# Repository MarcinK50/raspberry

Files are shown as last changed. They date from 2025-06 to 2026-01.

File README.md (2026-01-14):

# RPi Pico W + DHT22 + PMS5003 sensor

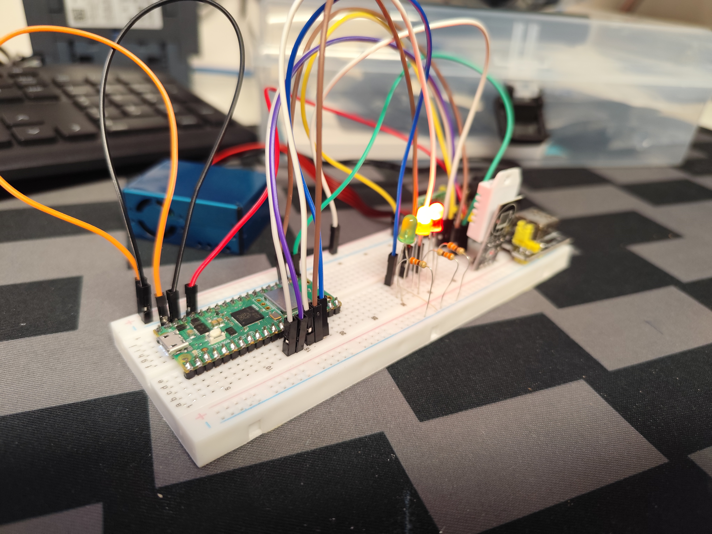
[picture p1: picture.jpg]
zdjecie


```
DHT22 - GPIO16
PMS5003 - TX GPIO8, RX GPIO9

status led:
power status (red) - GPIO10 
wifi status (yellow) - GPIO11
data status (green) - GPIO12
```

## Development branch - differences vs prod branch
- tables have `dev_` prefix
- another development dashboard on Grafana

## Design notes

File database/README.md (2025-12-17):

# Database
QuestDB database, set ip & port in config.py on sensor (default works on port 9000)

https://questdb.com/docs/quick-start/

## Database schema
- `config`
    - Columns:
    - `id` - sensor id `[int]`
    - `lat` - sensor latitude `[double]`
    - `lon` - sensor longitude `[double]`
    - `location` - sensor location, e.g. name of place or street `[string]`
    - `description` - more detalied info about sensor `[string]`
- `sensors`
    - Columns:
    - `timestamp`
    - `id` - sensor id corresponding with `id` from `config` table `[int]`
    - `temperature` `[double]`
    -  `humidity` `[double]`
    - `pm1` `[int]`
    - `pm25` `[int]`
    - `pm10` `[int]`
- `log` (work in progress)
    - Columns:
    - `id` `[int]`
    - `timestamp`
    - `code` - log message type, e.g. 0 - info, 1 - warning, 2 - error `[int]`
    - `message` - more detailed information `[string]`

## Quick configuration
Paste code from `configuration.sql` into QuestDB console to quickly create needed tables.

## Config example

```sql
INSERT INTO config (id, lat, lon, location, description) VALUES (0, 50.581867, 16.690958, 'Pracownia', 'Czujnik 1 w pracowni')
```

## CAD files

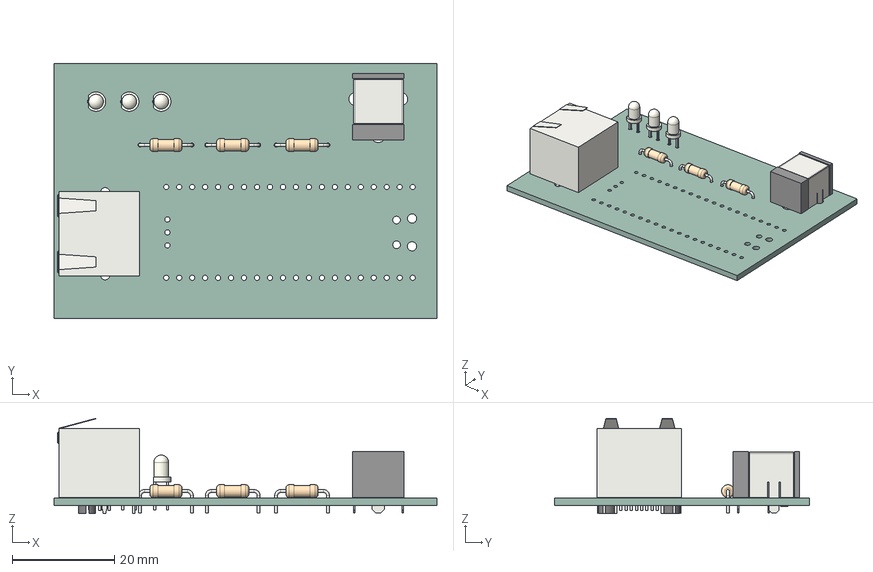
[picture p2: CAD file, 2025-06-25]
hardware/CAD/czujnik/czujnik.step
75.0 x 50.0 x 18.7 mm
BarrelJack_CUI_PJ-063AH_Horizontal
LED_D3.0mm_Clear x 3
Pico
RJ45_Amphenol_RJHSE538X
R_Axial_DIN0207_L6.3mm_D2.5mm_P10.16mm_Horizontal x 3
czujnik_PCB

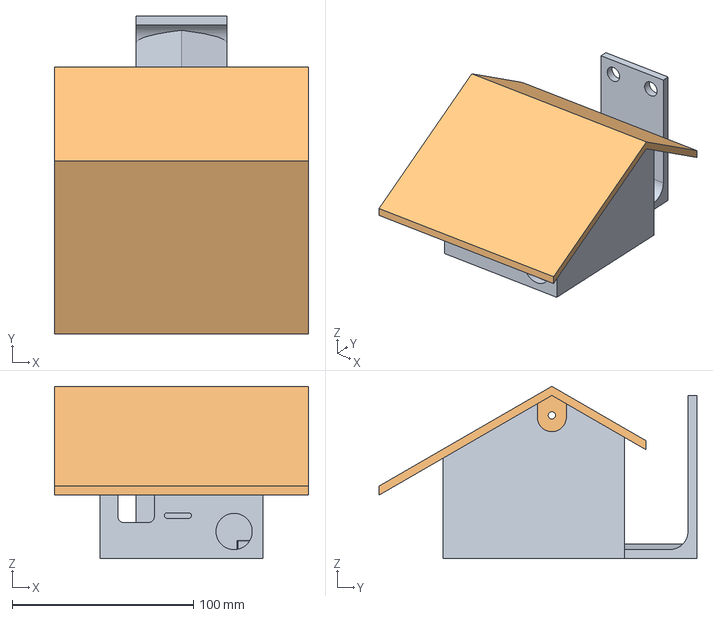
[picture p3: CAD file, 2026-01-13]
hardware/CAD/czujnik_external/Sensor_external.FCStd
140.0 x 175.3 x 95.0 mm
Cover
Roof

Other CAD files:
hardware/CAD/czujnik/czujnik.FCStd

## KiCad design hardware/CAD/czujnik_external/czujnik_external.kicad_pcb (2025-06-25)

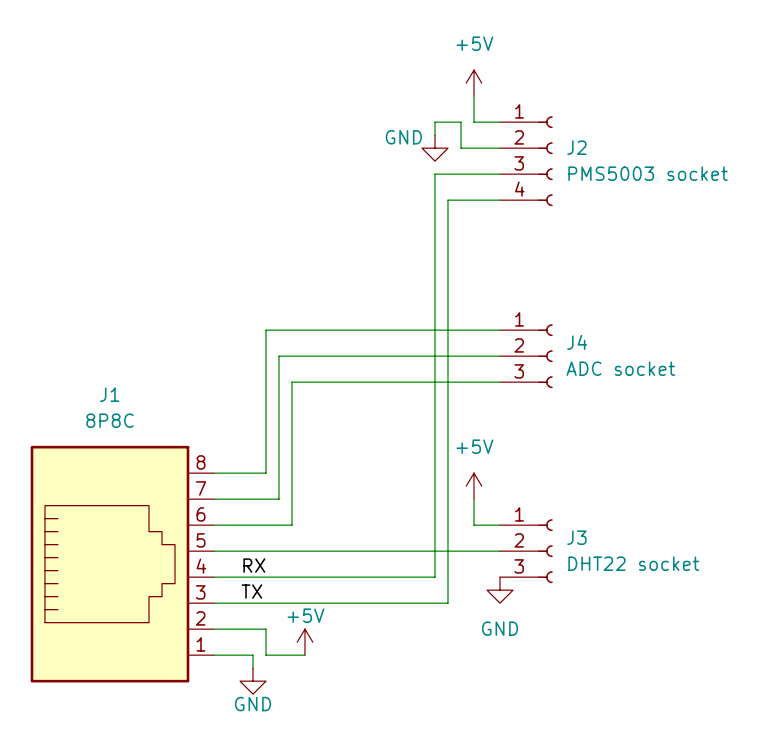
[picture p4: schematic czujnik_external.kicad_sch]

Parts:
J1: 8P8C; RJ45_Connfly_DS1128-09-S8xx-S_Horizontal
J2: PMS5003 socket; PinSocket_1x04_P2.54mm_Vertical
J3: DHT22 socket; PinSocket_1x03_P2.54mm_Vertical
J4: ADC socket; PinSocket_1x03_P2.54mm_Vertical

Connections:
+5V: J1.2, J2.1, J3.1
/RX: J1.4, J2.3
/TX: J1.3, J2.4
GND: J1.1, J2.2, J3.3
unnamed: J1.5, J3.2
unnamed: J1.8, J4.1
unnamed: J1.7, J4.2
unnamed: J1.6, J4.3

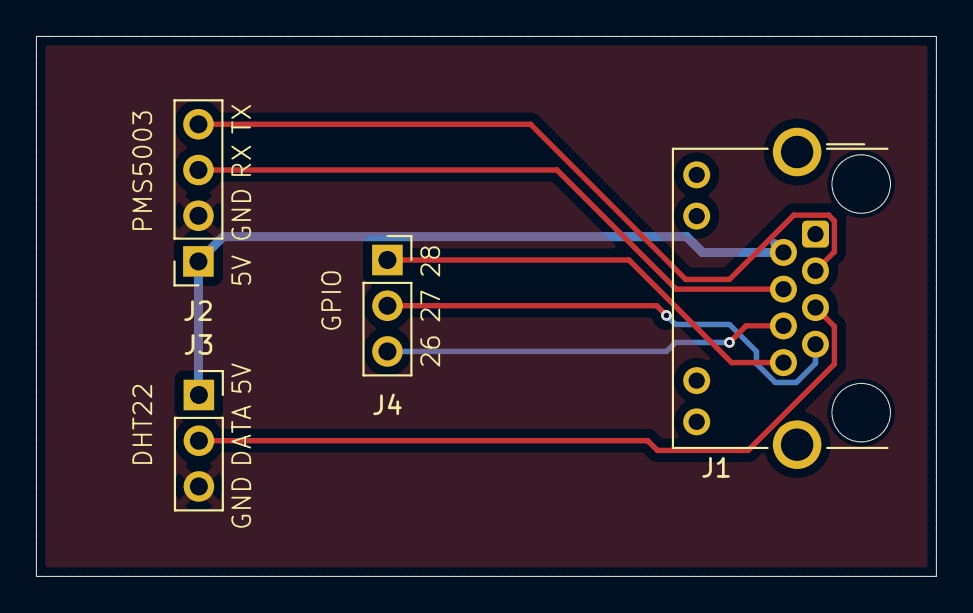
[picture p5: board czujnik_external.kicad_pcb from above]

Board: 2 copper layers, 50.0 x 30.0 mm, 4 parts (0 on the bottom side), 8 nets.

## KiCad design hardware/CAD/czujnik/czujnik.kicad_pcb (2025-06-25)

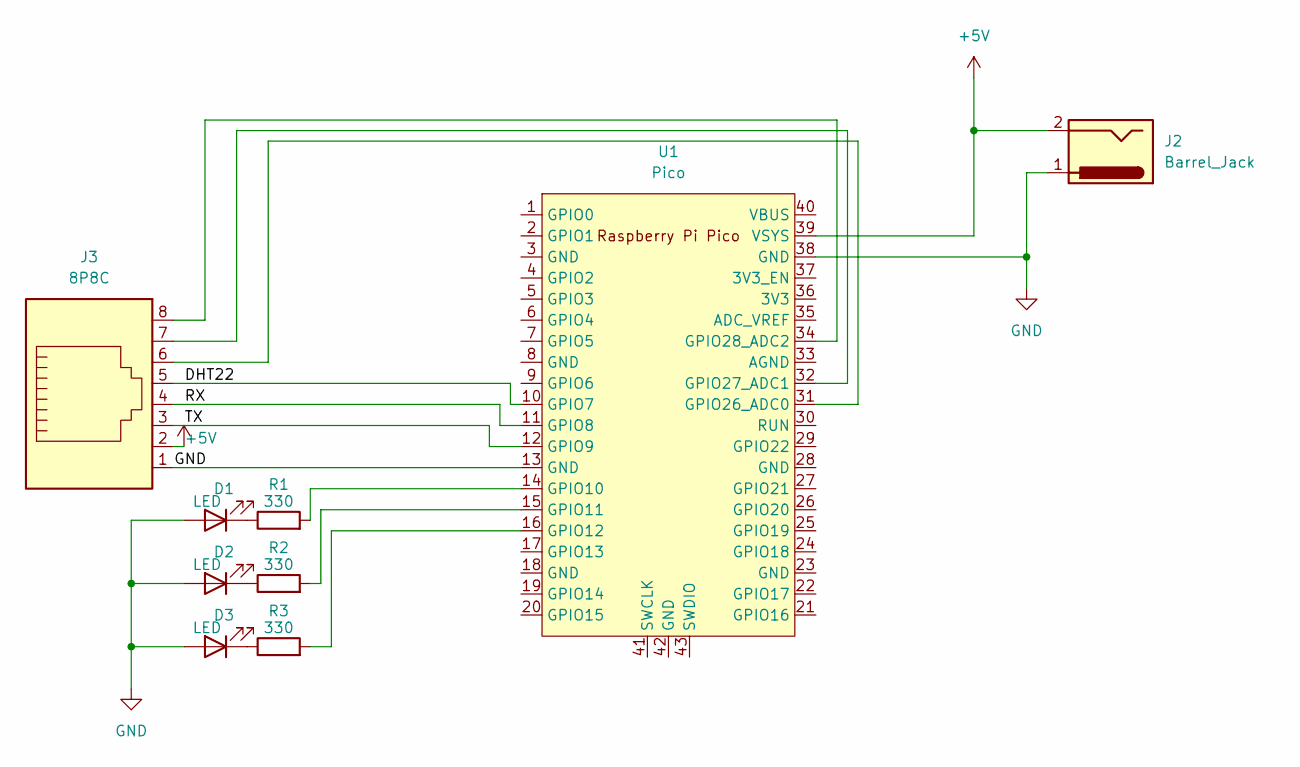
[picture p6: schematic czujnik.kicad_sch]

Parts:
D1, D2, D3: LED; LED_D3.0mm_Clear
J2: Barrel_Jack; BarrelJack_CUI_PJ-063AH_Horizontal_CircularHoles
J3: 8P8C; RJ45_Connfly_DS1128-09-S8xx-S_Horizontal
R1, R2, R3: 330; R_Axial_DIN0207_L6.3mm_D2.5mm_P10.16mm_Horizontal
U1: Pico; RPi_Pico_SMD_TH

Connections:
+5V: J2.2, J3.2, U1.39 (VSYS)
/DHT22: J3.5, U1.10 (GPIO7)
/RX: J3.4, U1.11 (GPIO8)
/TX: J3.3, U1.12 (GPIO9)
GND: D1.2 (A), D2.2 (A), D3.2 (A), J2.1, J3.1, U1.13 (GND), U1.38 (GND)
unnamed: D1.1 (K), R1.1
unnamed: D2.1 (K), R2.1
unnamed: D3.1 (K), R3.1
unnamed: R1.2, U1.14 (GPIO10)
unnamed: R2.2, U1.15 (GPIO11)
unnamed: R3.2, U1.16 (GPIO12)
unnamed: J3.6, U1.31 (GPIO26_ADC0)
unnamed: J3.7, U1.32 (GPIO27_ADC1)
unnamed: J3.8, U1.34 (GPIO28_ADC2)

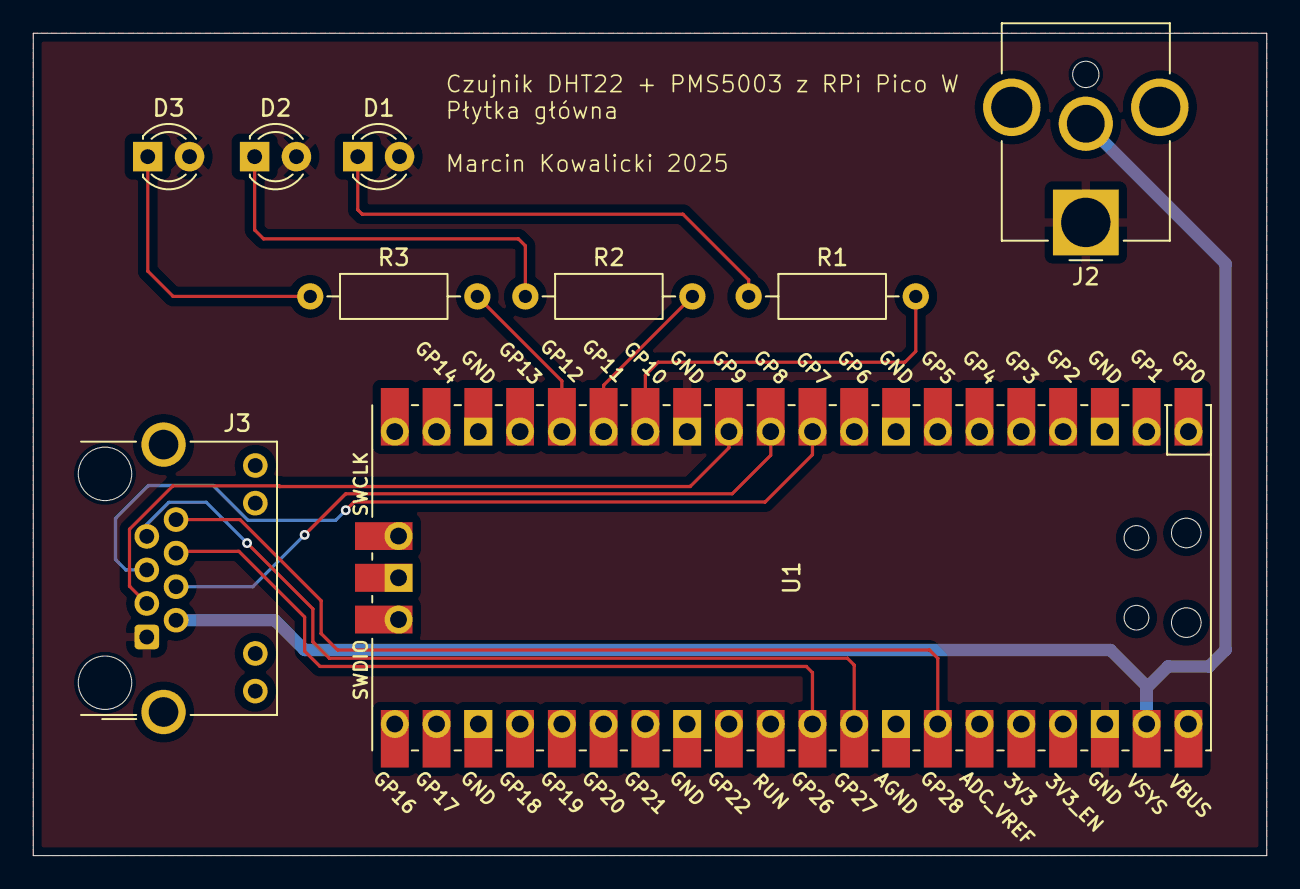
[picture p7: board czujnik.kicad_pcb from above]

Board: 2 copper layers, 75.0 x 50.0 mm, 9 parts (0 on the bottom side), 14 nets.

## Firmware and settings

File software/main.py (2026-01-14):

import utime, network, dht, mrequests as requests
from machine import Pin, UART
from pms5003 import PMS5003
import config
import ubinascii
import os
import ntptime, time
import gc

DO_DEBUG = True

SSID = config.ssid
PASSWORD = config.password
QUESTDB_USER = config.questdb_user
QUESTDB_PASSWORD = config.questdb_password

ID = config.location_id
IP, PORT = config.server_ip, config.server_port
UPDATE_RATE = config.update_rate
LOG_STATUS_OK = config.log_status_ok
MAX_LOG_FILESIZE = config.max_log_filesize
lat = config.lat
lon = config.lon
url = f"http://{IP}:{PORT}/exec"

power_led = Pin(10, Pin.OUT)
wifi_led = Pin(11, Pin.OUT)
data_led = Pin(12, Pin.OUT)
power_led.value(0)
wifi_led.value(0)
data_led.value(0)

sensor = dht.DHT22(Pin(16))
pms5003 = PMS5003(
    uart=UART(1, tx=Pin(8), rx=Pin(9), baudrate=9600),
    pin_enable=Pin(3),
    pin_reset=Pin(2),
    mode="active"
)

if config.status_led: power_led.value(1)

def connect_to_wifi(ssid,password):
    if DO_DEBUG:
        print('SSID: ', ssid)
        print('Pass: ', password)
    wlan = network.WLAN(network.STA_IF)
    wlan.active(True)
    if DO_DEBUG:    
        mac = ubinascii.hexlify(wlan.config('mac'),':').decode()
        print('MAC: ', mac)
        for w in wlan.scan():
            print(' * ', w[0].decode())        
    
    wlan.connect(SSID, PASSWORD)
    connection_timeout = config.wifi_timeout
    print('Connecting', end='')
    while connection_timeout > 0:
        if wlan.status() >= 3:
            break
        connection_timeout -= 1
        print('.', end='')
        utime.sleep(1)
    
    if wlan.status() != 3:
        log(2, 'Wi-Fi Connection error!')
        raise RuntimeError('Connection error')
    else:
        print('Connection successful!')
        try:
            ntptime.host = "0.pool.ntp.org"
            ntptime.settime()
        except:
            ntptime.host = "1.pool.ntp.org"
            ntptime.settime()
        log(0, 'Wi-Fi Connection successful!')
        if config.status_led: wifi_led.value(1)
        network_info = wlan.ifconfig()
        if DO_DEBUG:
            print('IP:', network_info[0])
       
def get_temperature():
    try:
        data = sensor.measure()
        temp = sensor.temperature()
        hum = sensor.humidity()
        print('Reading dht22 success!')
        print([temp,hum])
        return [temp, hum]
    except:
        print('Error reading dht22!')
        log(2, 'No data from DHT22')
        return ['NULL', 'NULL']

def get_pollution():
    try:
        pms = pms5003.read()
        pm1 = pms.data[0]
        pm25 = pms.data[1]
        pm10 = pms.data[2]
        print('Reading pms5003 success!') 
        print([pm1, pm25, pm10])
        return [pm1, pm25, pm10]
    except:
        print('Error reading pms5003!')
        log(2, 'No data from PMS5003')
        return ['NULL', 'NULL', 'NULL']
    
def log(code, message):
    timestamp = int(f'{time.time()}000000') # TODO: to convert timestamp from NTP to nanoseconds format, this is very sketchy, make it better
    
    log_filename = 'log-0.txt'
    log_files = []
    directory = os.listdir()
    for f in directory:
        if f.startswith('log'):
            if os.stat(f)[6] > MAX_LOG_FILESIZE:
                log_number = 0
                while True:
                    if f'log-{log_number}.txt' in directory and os.stat(f'log-{log_number}.txt')[6] > MAX_LOG_FILESIZE:
                        log_files.append(log_number)
                        log_number += 1
                    else: 
                        log_filename = f'log-{log_number}.txt'
                        break
            else: log_filename = f
    log_files = list(set(log_files))
    
    stat = os.statvfs("/")
    size = stat[1] * stat[2]
    free = stat[0] * stat[3]
    used = size - free
    print(f"Memory usage: {used/size*100}%")
    
    if used/size*100 > 80:
        print("Memory used too much! Deleting oldest logs")
        for log_number in log_files:
            os.remove(f'log-{log_number}.txt')
            
    file = open(log_filename, "a")
    file.write(f'{timestamp}, {code}, {message}\n')
    file.close()
    
    if DO_DEBUG:
        query = f"INSERT INTO dev_log (id,timestamp,code,message) VALUES ({ID},{timestamp},{str(code)},'{str(message)}')"
    else:
        query = f"INSERT INTO log (id,timestamp,code,message) VALUES ({ID},{timestamp},{str(code)},'{str(message)}')"
    log_url = url+"?query="+url_encode(query)
    if DO_DEBUG:
        print("[LOG] Executing query : ")
        print(log_url)
    try:
        requests.get(url=log_url, auth=(QUESTDB_USER, QUESTDB_PASSWORD))
        return 0
    except Exception as error:
        if str(error) == "Unsupported types for __add__: 'str', 'bytes'": return 0
        else:
            print("[LOG] General error: ",str(error))
            return 1

def url_encode(string):
    encoded_string = ''
    for char in string:
        if char.isalpha() or char.isdigit() or char in '-._~':
            encoded_string += char
        else:
            encoded_string += '%' + '{:02X}'.format(ord(char))
    return encoded_string

def send_results(ID,temperature, humidity, pm1, pm25, pm10):
    gc.collect()
    if DO_DEBUG:
        query = f"INSERT INTO dev_sensors(id,temperature,humidity,pm1,pm25,pm10,timestamp) VALUES('{ID}',{str(temperature)},{str(humidity)},{str(pm1)},{str(pm25)},{str(pm10)},{time.time()}000000)"
    else:
        query = f"INSERT INTO sensors(id,temperature,humidity,pm1,pm25,pm10,timestamp) VALUES('{ID}',{str(temperature)},{str(humidity)},{str(pm1)},{str(pm25)},{str(pm10)},{time.time()}000000)"
    full_url = url+"?query="+url_encode(query)
    
    
    if DO_DEBUG:
        print("Executing query : ")
        print(full_url)
    
    try:
        requests.get(url=full_url, auth=(QUESTDB_USER, QUESTDB_PASSWORD))
        return 0
    except Exception as error:
        if str(error) == "Unsupported types for __add__: 'str', 'bytes'": return 0
        else:
            print("General error: ",str(error))
            return 1

def main():
    connect_to_wifi(SSID,PASSWORD)
    status_timer = 0
    while True:
        temperature, humidity = get_temperature()
        pm1, pm25, pm10 = get_pollution()
        response = send_results(ID,temperature, humidity, pm1, pm25, pm10)
        while response != 0:
            response = send_results(ID,temperature, humidity, pm1, pm25, pm10)
            print("Sending : ",response)
            utime.sleep(1)
        if config.status_led:
            data_led.value(1)
            utime.sleep(1)
            data_led.value(0)
        
        if status_timer == LOG_STATUS_OK:
            log(0, 'OK')
            status_timer = 0
        else: status_timer += 1
        utime.sleep(UPDATE_RATE)

main()

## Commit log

2025-06-19 poprawka importowania biblioteki od UART
2025-06-22 dodanie mozliwosci wylaczenia LED statusu czujnika
2025-06-25 dodanie plikow CAD
    [czujnik.FCStd, czujnik.kicad_pcb, czujnik.kicad_sch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]
2025-11-19 better error handling, add lat and lon fields
    [main.py]
2025-12-02 Small corrections, Style update, Comments, More debug info
    [main.py]
2025-12-17 add database schema, cleanup git repo
    [czujnik.FCStd, czujnik.kicad_pcb, czujnik.kicad_sch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]
2025-12-20 fix getting time from NTP, improve logging
    [main.py]
2025-12-21 fix memory issues when sending request by implementing garbage collector
    [main.py]
2026-01-07 fix issues with log numbering, implement removing old logs when memory is used
    [main.py]
2026-01-07 fix merge from previous commit
    [main.py]
2026-01-08 External Sensor Cover
    [Sensor_external.FCStd]
2026-01-13 External Sensor Cover additions
    [Sensor_external.FCStd]
